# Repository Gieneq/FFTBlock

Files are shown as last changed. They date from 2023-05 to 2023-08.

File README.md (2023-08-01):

# FFTslice

Module to evaluate FFT. Communication with SPI. PGA for gain control. 2 selectable channels, additional DAC channel for selftest.

<p align="center">
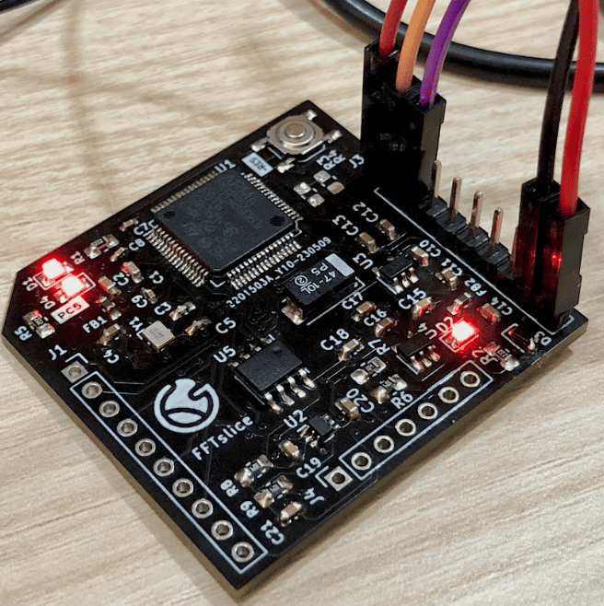
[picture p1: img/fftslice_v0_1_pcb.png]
FFTSlice PCB V0.1
    
</p>

## DAC samples generation

See [notebook](Doc/DAC_samples/FFTSlice_DAC.ipynb) with all calculations. 

Frequencies from 20 Hz to 20 kHz are splitted into 100 ranges in logspace to better fit sound perception. 

<p align="center">
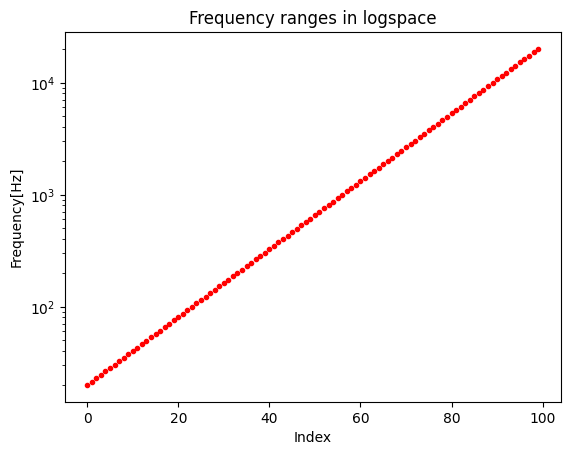
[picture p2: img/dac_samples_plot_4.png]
plot 1
    
</p>

3 variables affects output DAC frequency:
- constant TIM1 clock = 64 MHz,
- variable divider
- samples count

Divider can be freely changed, but samples count have to be generated in advance and stored in FLASH. There are 6 samples counts: 64, 128, 256, 512, 1024 and 2048. Higher samples counts fits better to generate low frequencies, lower samples counts are better fot higher frequencies.

<p align="center">
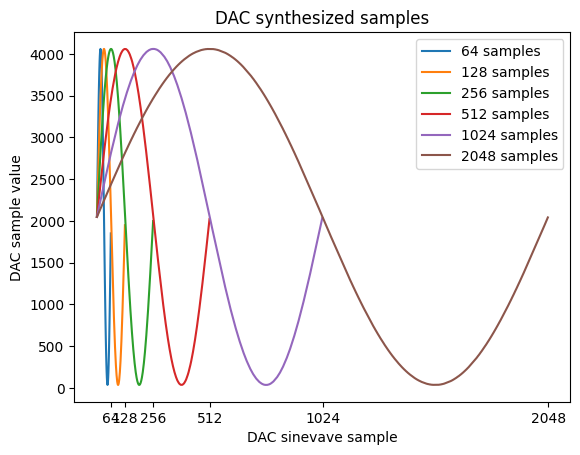
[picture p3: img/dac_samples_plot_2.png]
plot 2
    
</p>

100 parameters are calculated so that samples count and divider lowers time in which output voltage remain the same, and deviation from theoretical frequency is acceptable.

Resulting error remains below 1% as seen in the plot:

<p align="center">
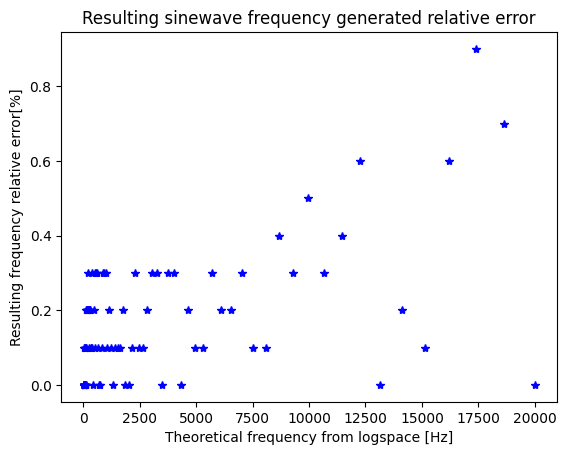
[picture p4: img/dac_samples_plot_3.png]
resulting relative error
    
</p>

Matching of samples counts is more or less proportional:

<p align="center">
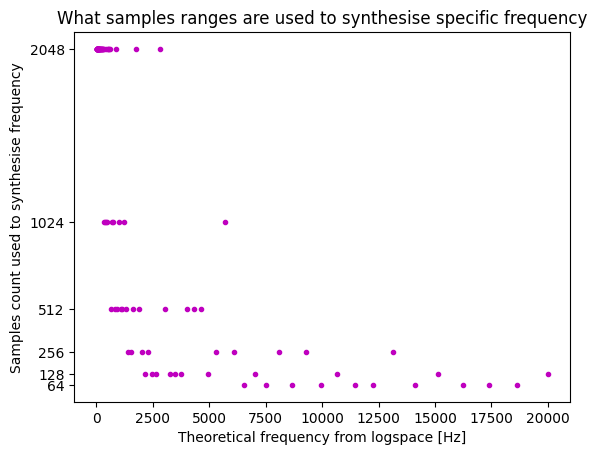
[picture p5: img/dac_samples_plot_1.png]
matching samples counts
    
</p>

Resulting frequencies are very close to theoretically calculated. In the plot sinewave with output buffer enabled without low pass filter:

<p align="center">
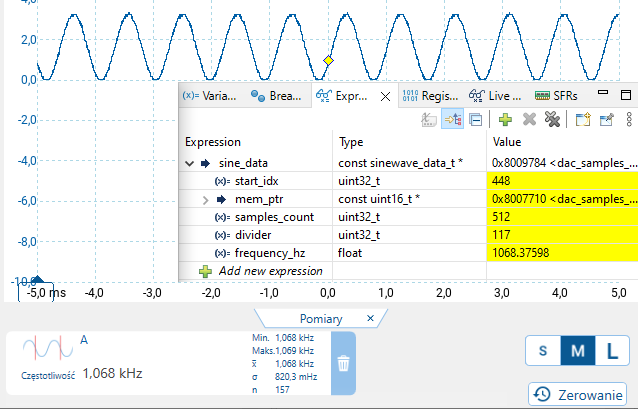
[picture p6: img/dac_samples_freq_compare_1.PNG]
Output frequency comparison
    
</p>

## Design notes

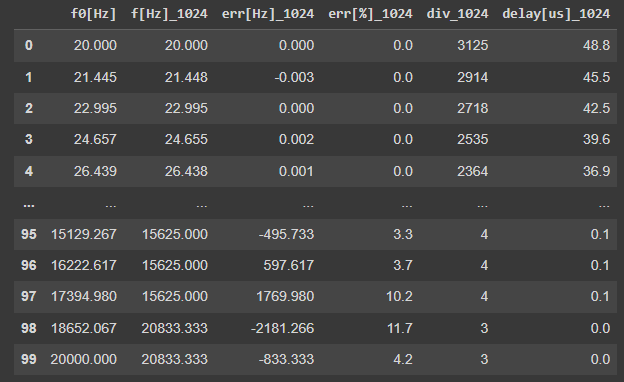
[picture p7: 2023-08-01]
img/dac_samples_table_1.PNG

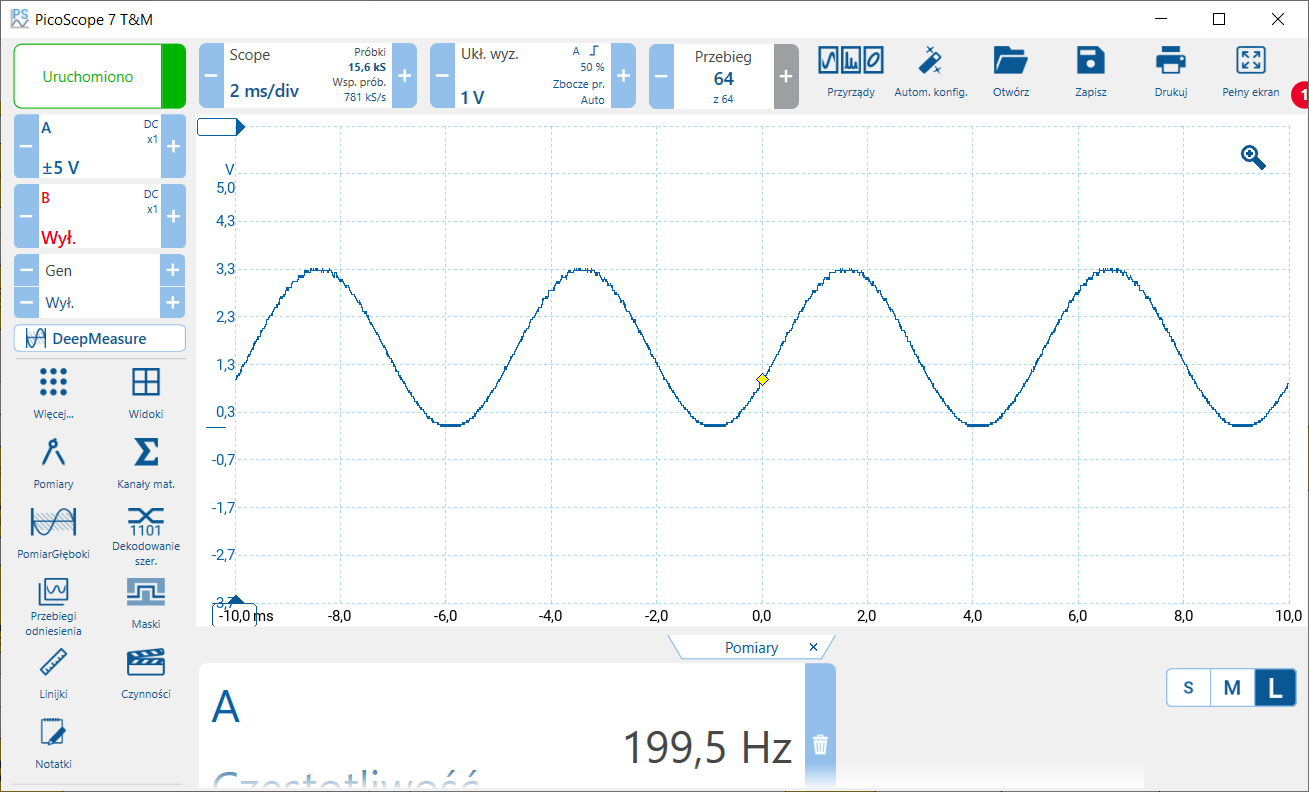
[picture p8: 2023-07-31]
img/dac_313_1024_199_7Hz.PNG

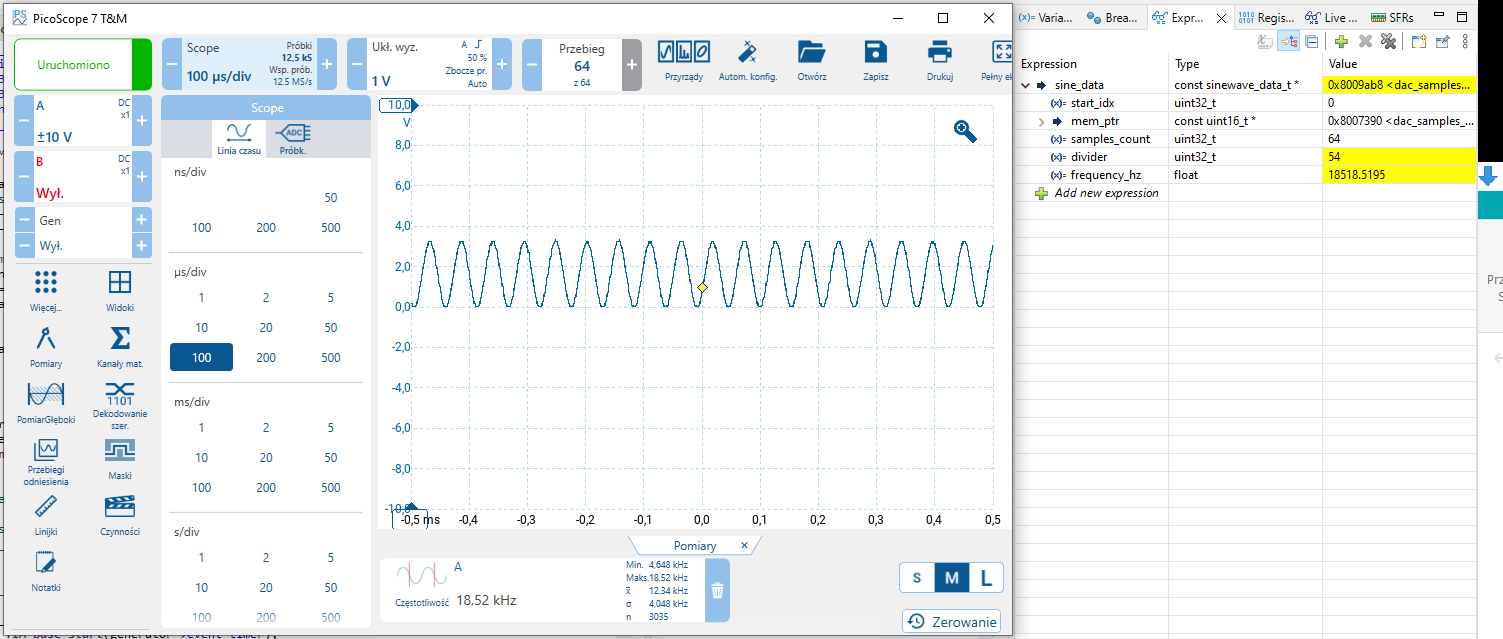
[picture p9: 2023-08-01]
Doc/DAC_samples/freq_7.PNG

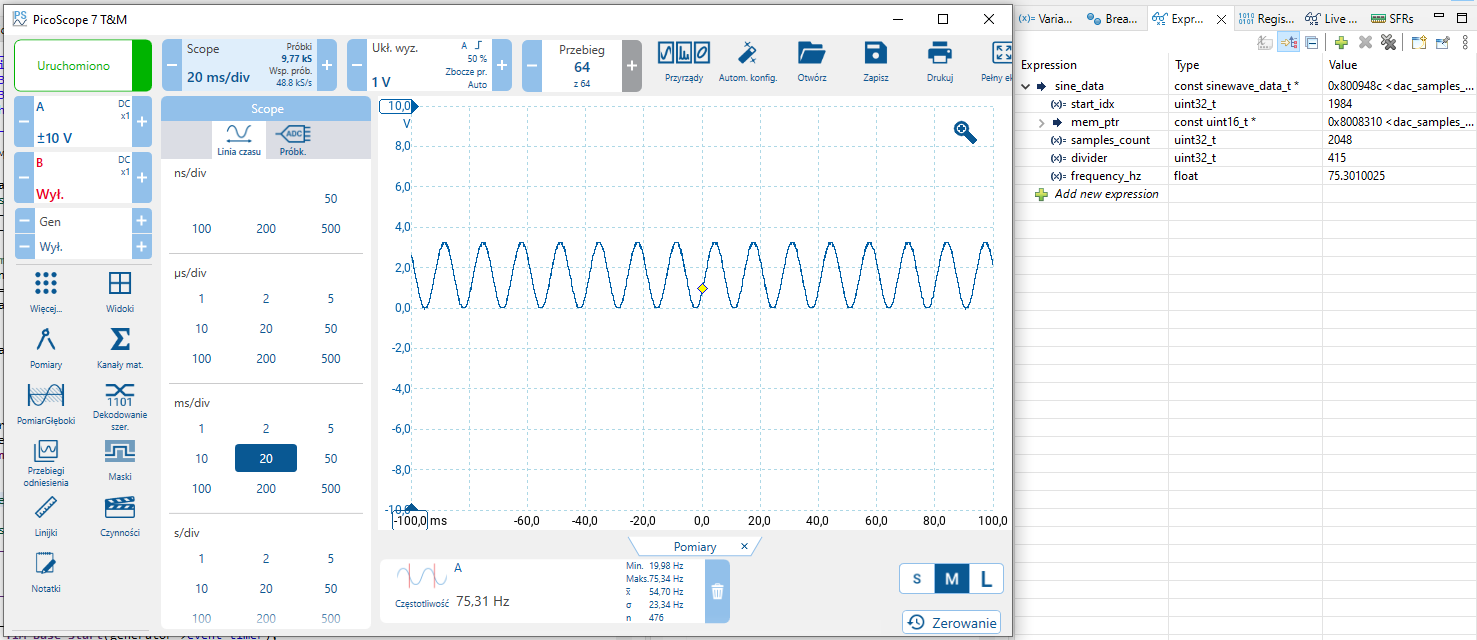
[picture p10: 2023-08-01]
Doc/DAC_samples/freq_1.PNG

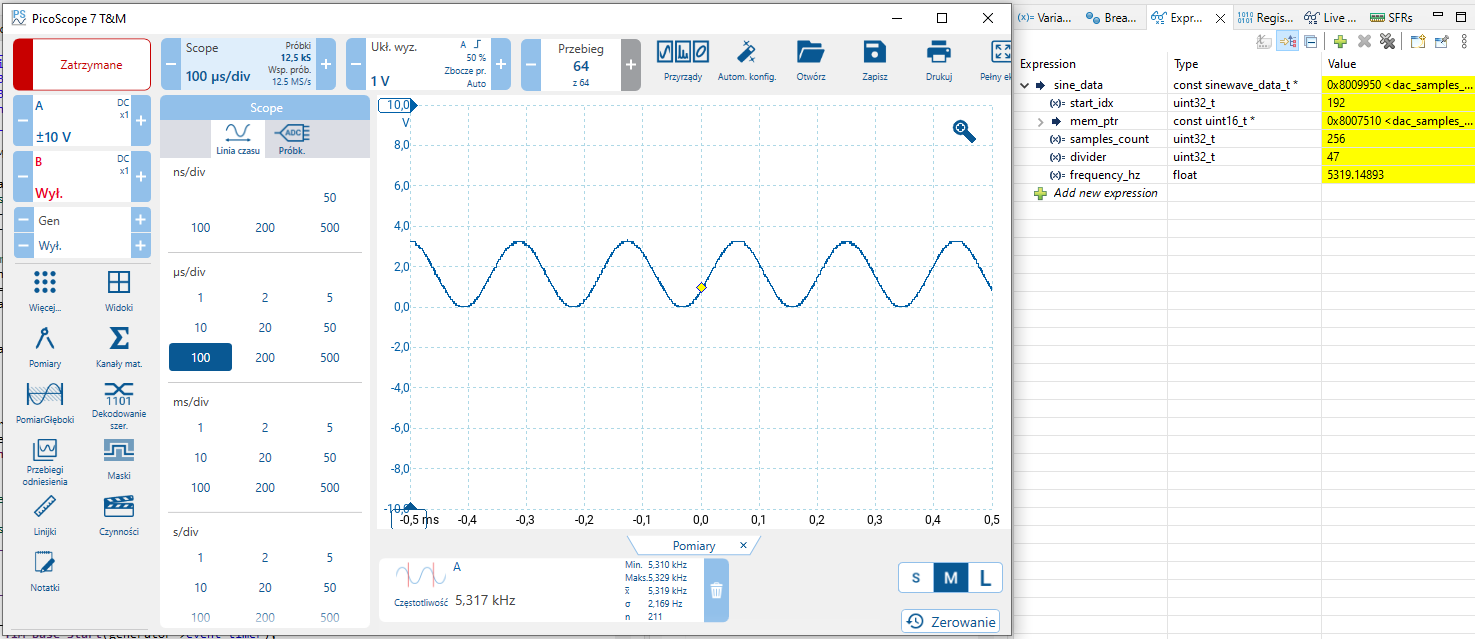
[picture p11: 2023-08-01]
Doc/DAC_samples/freq_5.PNG

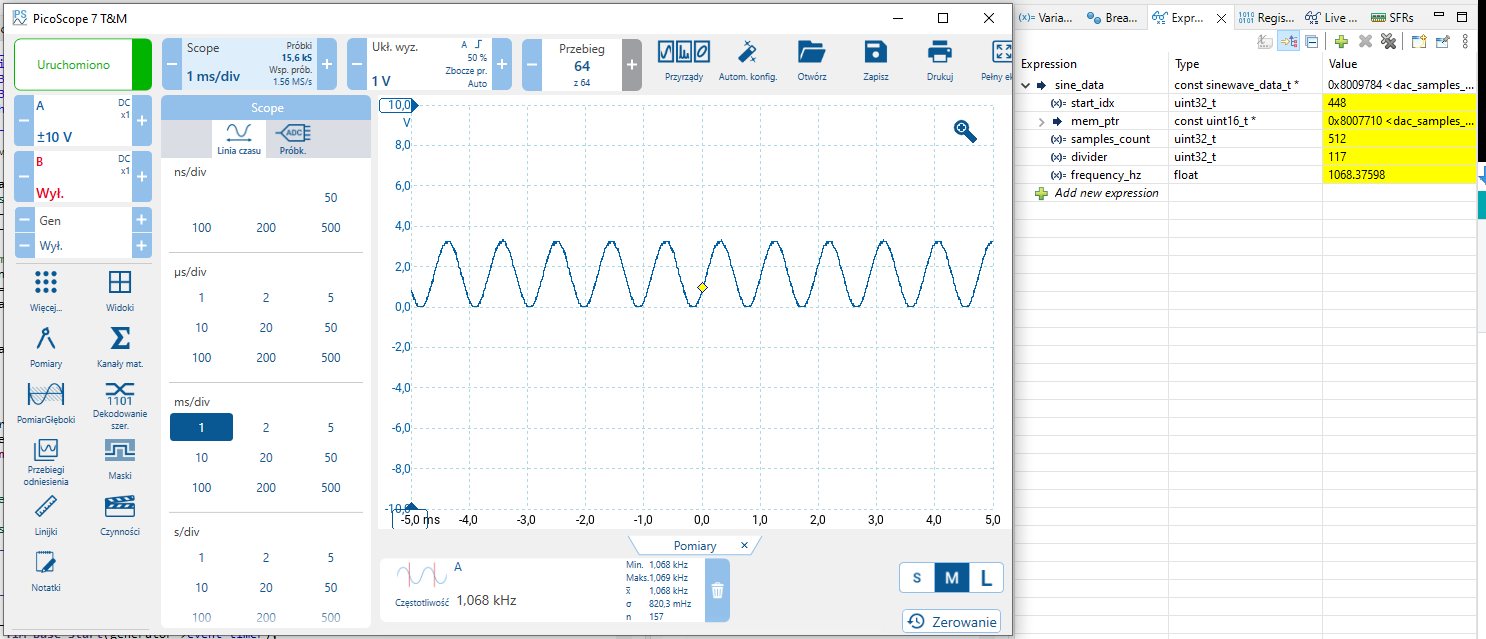
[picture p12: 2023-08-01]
Doc/DAC_samples/freq_3.PNG

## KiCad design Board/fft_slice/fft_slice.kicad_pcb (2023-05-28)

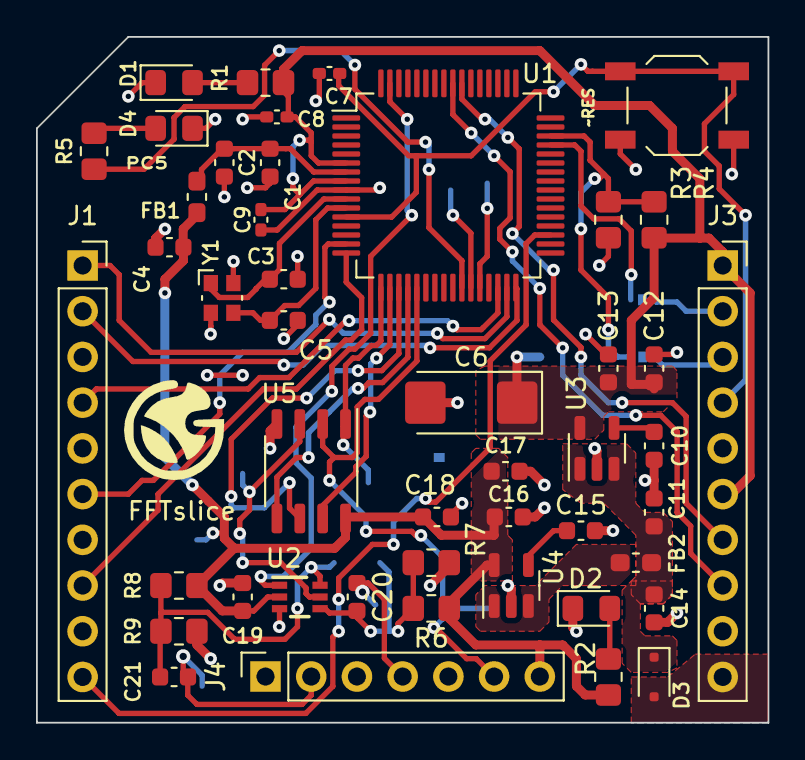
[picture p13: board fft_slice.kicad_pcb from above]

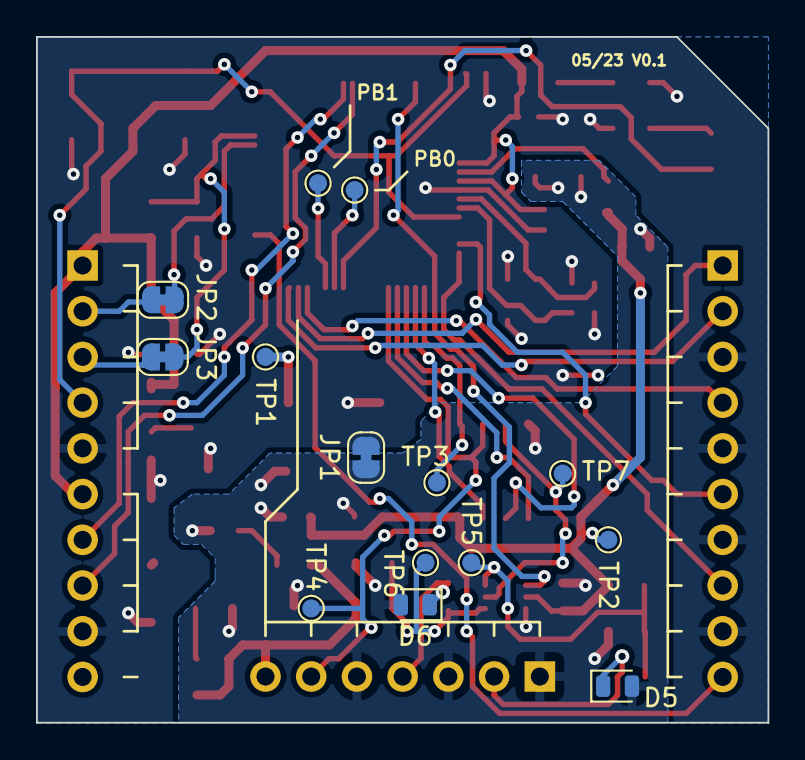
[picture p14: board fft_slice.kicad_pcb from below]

Board: 2 copper layers, 40.6 x 38.1 mm, 60 parts (14 on the bottom side), 42 nets.

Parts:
C1, C10, C15, C19: 10nF; C_0603_1608Metric
C2, C13, C14, C17, C20, C21: 1uF; C_0603_1608Metric
C3, C5: 10pF; C_0603_1608Metric
C4, C11, C12, C16, C18: 100nF; C_0603_1608Metric
C6: 100uF; CP_EIA-6032-15_Kemet-U_Pad2.25x2.35mm_HandSolder
C7, C8, C9: 100nF; C_0402_1005Metric_Pad0.74x0.62mm_HandSolder
D1, D2, D4: LED; LED_0805_2012Metric_Pad1.15x1.40mm_HandSolder
D3: PMEG2005EJ; D_SOD-323F
D5, D6: BZM55C3V3; D_MicroMELF
FB1, FB2: 120R@100MHz; L_0603_1608Metric_Pad1.05x0.95mm_HandSolder
J1, J3: Conn_01x10; PinSocket_1x10_P2.54mm_Vertical
J4: Conn_01x07; PinSocket_1x07_P2.54mm_Vertical
JP1, JP2, JP3: SolderJumper-2_P1.3mm_Bridged_RoundedPad1.0x1.5mm
R1, R2, R3, R5: 4k7; R_0805_2012Metric_Pad1.20x1.40mm_HandSolder
R4: NA; R_0805_2012Metric_Pad1.20x1.40mm_HandSolder
R6, R7, R8, R9: 100k; R_0805_2012Metric_Pad1.20x1.40mm_HandSolder
SW1: RESET; SW_SPST_TL3342
TP1, TP2, TP3, TP4, TP5, TP6, TP7, TP8, TP9: TestPoint; TestPoint_Pad_D1.0mm
U1: STM32G081RBTx; LQFP-64_10x10mm_P0.5mm
U2: TS5A9411DCKR; DCK0006A_N
U3, U4: SPX3819M5-L-3-3; SOT-23-5
U5: MCP6S22-I_MS; SOP-8_3.9x4.9mm_P1.27mm
Y1: 16MHz 10pF; Crystal_SMD_Abracon_ABM10-4Pin_2.5x2.0mm

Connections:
+3.3V: C6.1, C8.1, C9.1, C12.1, C13.1, J3.1, J3.6, R1.2, R4.1, TP1.1, U1.6 (VBAT), U1.8 (VDD), U3.5 (OUT)
+3.3VA: C4.1, C16.1, C17.1, C18.1, C19.1, FB1.1, J4.7, R2.2, R6.1, R8.1, TP2.1, U2.2 (V+), U4.5 (OUT), U5.8 (VDD)
+5V: D3.2 (A), J3.10
/Analog/EXTRN_SIG_SELECTED: TP7.1, U2.5 (COM), U5.3 (CH1)
/MCU/BOOT0: JP3.1 (A), R3.1, R4.2, U1.46 (PA14)
/MCU/OSC_IN: C3.1, U1.10 (PF0), Y1.1
/MCU/OSC_OUT: C5.1, U1.11 (PF1), Y1.3
/Power_Supply/5V SAFE: C11.1, C14.1, D3.1 (K), FB2.2, U3.1 (IN), U3.3 (EN)
/Power_Supply/5V_SAFE_FB: FB2.1, U4.1 (IN), U4.3 (EN)
ADC_SIG: TP3.1, U1.17 (PA0), U5.1 (VOUT)
DAC_SIG: J4.6, TP4.1, U1.21 (PA4), U5.2 (CH0)
DEV_MISO: J1.6, U1.15 (PC2)
DEV_MOSI: J1.8, U1.16 (PC3)
DEV_N_CS: J1.10, U1.35 (PB15)
DEV_N_INT: J1.2, U1.32 (PB12)
DEV_R_NW: J1.1, U1.31 (PB11)
DEV_SCK: J1.4, U1.30 (PB10)
EXTRN_SIG_1: C20.1, D6.1 (K), J4.4
EXTRN_SIG_2: C21.1, D5.1 (K), J4.2
EXTRN_SIG_SEL: U1.63 (PB9), U2.1 (IN)
GND: C3.2, C5.2, C6.2, C7.2, C8.2, C9.2, C10.2, C11.2, C12.2, C13.2, C14.2, D1.1 (K), D4.1 (K), J1.3, J1.5, J1.7, J1.9, J3.5, J3.9, JP1.1 (A), R3.2, SW1.2, U1.9 (VSS), U3.2 (GND), Y1.2, Y1.4
GNDA: C1.2, C2.2, C4.2, C15.2, C16.2, C17.2, C18.2, C19.2, D2.1 (K), D5.2 (A), D6.2 (A), J4.1, J4.3, J4.5, JP1.2 (B), R7.2, R9.2, U2.3 (GND), U4.2 (GND), U5.4 (VSS)
NRST: C7.1, J3.4, SW1.1, U1.12 (PF2)
unnamed: D1.2 (A), R1.1
unnamed: D2.2 (A), R2.1
unnamed: D4.2 (A), R5.2
unnamed: JP2.1 (A), U1.45 (PA13)
unnamed: TP8.1, U1.27 (PB0)
unnamed: TP9.1, U1.28 (PB1)
unnamed: R5.1, U1.26 (PC5)
unnamed: C1.1, C2.1, FB1.2, U1.7 (VREF+)
unnamed: C20.2, R6.2, R7.1, TP6.1, U2.4 (NC)
unnamed: C21.2, R8.2, R9.1, TP5.1, U2.6 (NO)
unnamed: C10.1, U3.4 (BP)
unnamed: C15.1, U4.4 (BP)
PGA_MOSI: U1.19 (PA2), U5.6 (SI)
PGA_N_CS: U1.20 (PA3), U5.5 (~CS)
PGA_SCK: U1.18 (PA1), U5.7 (SCK)
SWDCLK: J3.3, JP3.2 (B)
SWDIO: J3.2, JP2.2 (B)
UART2_RX: J3.8, U1.56 (PD6)
UART2_TX: J3.7, U1.55 (PD5)

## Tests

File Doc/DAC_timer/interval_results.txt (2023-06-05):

Source clock 64.0 MHz
n_smpls   f_tar[Hz]     div         t[us]
16        20            200000.0    3125.0
16        30000.0       133.33      2.083
32        20            100000.0    1562.5
32        30000.0       66.67       1.042
64        20            50000.0     781.25
64        30000.0       33.33       0.521
128       20            25000.0     390.625
128       30000.0       16.67       0.26
256       20            12500.0     195.312
256       30000.0       8.33        0.13
512       20            6250.0      97.656
512       30000.0       4.17        0.065
1024      20            3125.0      48.828
1024      30000.0       2.08        0.033
2048      20            1562.5      24.414
2048      30000.0       1.04        0.016

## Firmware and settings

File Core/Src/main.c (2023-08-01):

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
/* Includes ------------------------------------------------------------------*/
#include "main.h"
#include "adc.h"
#include "dma.h"
#include "spi.h"
#include "tim.h"
#include "usart.h"
#include "gpio.h"

/* USER CODE BEGIN Includes */
#include "fftslice.h"
#include "dac_sines.h"

/* USER CODE END Includes */


/* USER CODE BEGIN PV */
fftslice_t fftslice;
/* USER CODE END PV */

void SystemClock_Config(void);
/**
  * @brief  The application entry point.
  * @retval int
  */
int main(void)
{
  /* MCU Configuration--------------------------------------------------------*/

  /* Reset of all peripherals, Initializes the Flash interface and the Systick. */
  HAL_Init();

  /* Configure the system clock */
  SystemClock_Config();

  /* Initialize all configured peripherals */
  MX_GPIO_Init();
  MX_DMA_Init();
  MX_ADC1_Init();
  MX_SPI1_Init();
  MX_SPI2_Init();
  MX_USART2_UART_Init();
  MX_TIM1_Init();
  /* USER CODE BEGIN 2 */

  fftslice_config_t fftslice_config;
  fftslice_config.mcp6s22_ncs_pin = PGA_N_CS_Pin;
  fftslice_config.mcp6s22_ncs_port = PGA_N_CS_GPIO_Port;
  fftslice_config.mcp6s22_spi = &hspi1;
  fftslice_config.ts5a9411_select_sig_pin = EXT_SIG_SELECT_Pin;
  fftslice_config.ts5a9411_select_sig_port = EXT_SIG_SELECT_GPIO_Port;

  fftslice_init(&fftslice, &fftslice_config);

  /* USER CODE END 2 */

  /* Infinite loop */
  /* USER CODE BEGIN WHILE */
 int freq_index = 0;
  while (1)
  {
	 HAL_GPIO_TogglePin(LED_GPIO_Port, LED_Pin);
	 HAL_Delay(2000);

	 if(freq_index >= DAC_FREQ_STEPS) {
		 freq_index = 0;
	 }
	 sig_generator_set(&fftslice.generator, freq_index);
	 ++freq_index;

    /* USER CODE END WHILE */

    /* USER CODE BEGIN 3 */
  }
  /* USER CODE END 3 */
}

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


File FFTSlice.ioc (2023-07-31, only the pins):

Mcu.UserName=STM32G081RBTx
PA0.Signal=ADC1_IN0
PA1.Signal=SPI1_SCK
PA13.Signal=SYS_SWDIO
PA14-BOOT0.Signal=SYS_SWCLK
PA2.Signal=SPI1_MOSI
PA3.GPIO_Label=PGA_N_CS
PA3.Signal=GPIO_Output
PA4.Signal=COMP_DAC11_group
PB10.Signal=SPI2_SCK
PB15.GPIO_Label=DEV_N_CS
PB15.Signal=GPXTI15
PB9.GPIO_Label=EXT_SIG_SELECT
PB9.Signal=GPIO_Output
PC2.Signal=SPI2_MISO
PC3.Signal=SPI2_MOSI
PC5.GPIO_Label=LED
PC5.Signal=GPIO_Output
PD5.Signal=USART2_TX
PD6.Signal=USART2_RX

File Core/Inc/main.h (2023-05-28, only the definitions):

#define PGA_N_CS_Pin GPIO_PIN_3
#define PGA_N_CS_GPIO_Port GPIOA
#define LED_Pin GPIO_PIN_5
#define LED_GPIO_Port GPIOC
#define DEV_N_CS_Pin GPIO_PIN_15
#define DEV_N_CS_GPIO_Port GPIOB
#define EXT_SIG_SELECT_Pin GPIO_PIN_9
#define EXT_SIG_SELECT_GPIO_Port GPIOB

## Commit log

2023-05-28 MCP6S22 component driver
    [analog.kicad_sch, fft_slice.kicad_pcb, fft_slice.kicad_sch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]
2023-05-29 Device driver initial
2023-06-05 Folders rework, add timer calculations
    [FFTSlice.ioc, fftslice.c, main.c]
2023-08-01 Working DAC samples

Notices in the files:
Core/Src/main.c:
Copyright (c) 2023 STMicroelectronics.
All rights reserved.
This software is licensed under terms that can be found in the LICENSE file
